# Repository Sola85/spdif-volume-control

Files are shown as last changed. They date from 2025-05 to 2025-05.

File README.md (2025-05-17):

# SPDIFVolumeControl
### What?
This is an Arduino sketch for a Raspberry Pi Pico that reads TOSLINK or SPDIF audio data, modifies the volume, and writes the audio data to a second TOSLINK/SPDIF port. The volume can be adjusted by an IR remote. Optionally the current volume and a VU meter can be displayed on a WS2812 LED strip.

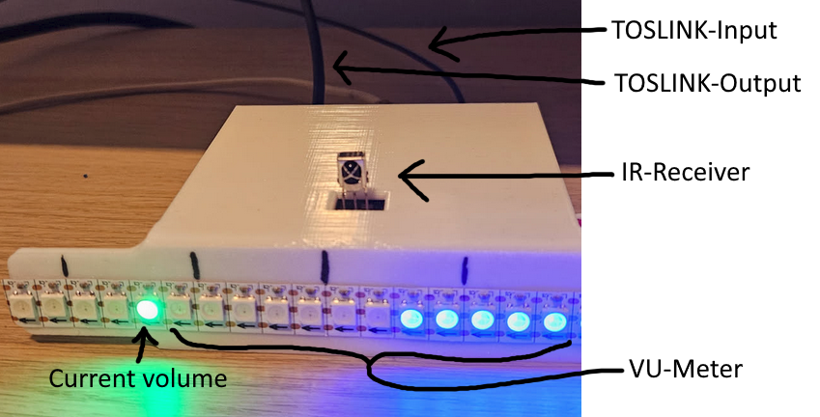
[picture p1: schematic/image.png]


### Why?
I'm in a peculiar situation: I want to connect my LG "Smart" TV to my Logitech PC speakers. However, the smart TV has only 3 types of audio outputs:

1. TOSLINK
2. HDMI ARC
3. Bluetooth 

In particular, it doesn't have an analog output. Using Bluetooth to connect to the speaker is not an option, since I don't want to deal with the hassle of always making sure a wireless connection is established. 
The Logitech speakers support various types of analog input, as well as TOSLINK. Which sounds fine, however the TV refuses to control the volume of the speakers when they are connected via TOSLINK. Since my speakers don't have a separate remote, I'm stuck.

Hence this project was born. It is designed to forward TOSLINK audio from the TV to the speakers while intercepting IR signals of the TV remote, allowing me to adjust the volume!

I'm aware that this method of adjusting the volume can:
- lead to loss of quality when significantly reducing the volume and 
- can lead to distortions when amplifying the volume.

The first point is not an issue for a non-audiophile like me. If the analog volume knob of the speaker is set to a value such that the unmodified signal is close to the target volume, I only need to adjust the volume a few increments above or below this. This typicalls leads to a quality loss of at most ~2 bits, which I can't notice. Distortions due to clipping would be more impactful, but these can be avoided by simply not amplifying the source signal using this method or by only amplifying when the source signal is very quiet.

### Compiling/Modifying

I used the following software versions to compile this project:
| Component | Version |
|---|---|
| Arduino IDE | 2.3.4 |
| [Raspberry Pi Pico Core](https://github.com/earlephilhower/arduino-pico) | 4.4.4 |
| [arduino-audio-tools](https://github.com/pschatzmann/arduino-audio-tools) | 1.0.1 (early 2025) |
| [IRremote](https://github.com/Arduino-IRremote/Arduino-IRremote) | 4.4.1 |
| [Adafruit_NeoPixel](https://github.com/adafruit/Adafruit_NeoPixel) |  1.12.5 |

Download the `code` folder and the contents should directly compile as an Arduino sketch, provided that the above dependencies are installed.

See `schematic/schematic.pdf` for wiring details.

Link to the 3D model [here](https://cad.onshape.com/documents/30e0986ab7bef6b26c69f87a/w/68a5b29d9b0bd2b4bf7dde1c/e/23cf1baabf4b8192e4efa997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).

### Usage

- Connect TOSLINK to the TV and Speakers as per schematic.
- A single orange/green led on the strip indicates the set volume. Each LED represents half an effective bit (ENOB), on a range from 17 ENOBs to 7 ENOBs.
- If a signal is detected on the input, the on board LED will start blinking and the volume indicator on the LED strip will turn from orange to green.
- The (volume-adjusted) input signal is displayed on the led strip as a VU Meter, again in the units of ENOB.

### Notes

- Currently supports **16-bit 44.1/48 kHz audio**, as this is the format my TV outputs.
- `pico_spdif_rx` should support 24-bit and higher sample rates, but the transmit side (audio-tools) is currently limited to 16-bit.
- IR control is configured for my **LG Magic Remote**, but adapting it to any protocol supported by `IRremote` should be straightforward.

### Libraries

The heavy-lifting is done by [arduino-audio-tools](https://github.com/pschatzmann/arduino-audio-tools) for transmitting and by [pico_spdif_rx](https://github.com/elehobica/pico_spdif_rx/) for receiving SPDIF signals.

I have included parts of the source of both of these libraries in this repo to accomodate a few minor changes that were necessary to get everything to work together. Despite being included in this repo, these libraries were not written by me and I do not claim ownership of them. More details are in the individual README's.

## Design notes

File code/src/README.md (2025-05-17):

# spdif_rx (modified version)

This folder contains a (minimally modified) version of the of the open-source library `pico_spdif_rx`. This was done since `pico_spdif_rx` is not available as an Arduino library and because slight modifications were necessary in order for it to work in this project.

---

## Original Library

- **Author**: Elehobica
- **Repository**: [https://github.com/elehobica/pico_spdif_rx/](https://github.com/elehobica/pico_spdif_rx/)
- **License**: BSD-2-Clause license 

---

## Modifications Made

- Adoptions of pio program according to comments in order to work with 192MHz CPU frequency
- Modification of `#include` paths, in order for Arduino IDE to be able to work with the library
- switch to `#define PICO_SPDIF_RX_DMA_IRQ 1` and `#define PICO_SPDIF_RX_PIO 1` since spdix tx uses PIO 0 and the corresponding DMA channel
- Removal of `pio_clear_instruction_memory(spdif_rx_pio);` in line 435 of `spdif_rx.cpp` as this seems to affect both PIO blocks, even though only one is passed to the function.
- rename `SPDIF_BLOCK_SIZE` as this gobal variable name is also used by spdif tx.
- Use of `pio_get_dreq` instead of manual logic for determining dreq. 
- Print-debugging

No functional or structural changes were made beyond this.

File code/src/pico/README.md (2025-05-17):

# pico-extras (modified excerpt)

This folder contains a (minimally modified) parts of the of the open-source library `pico-extras`. This was done since `pico-extras` is not available as an Arduino library (at least not that I am aware of).

---

## Original Library

- **Author**: Raspberry Pi Foundation
- **Repository**: [https://github.com/raspberrypi/pico-extras/](https://github.com/raspberrypi/pico-extras/)
- **License**: BSD-3-Clause license

---

## Modifications Made

- Deletions of files not necessary for this project
- Modification of `#include` paths, in order for Arduino IDE to be able to work with the library

No functional or structural changes were made beyond this.

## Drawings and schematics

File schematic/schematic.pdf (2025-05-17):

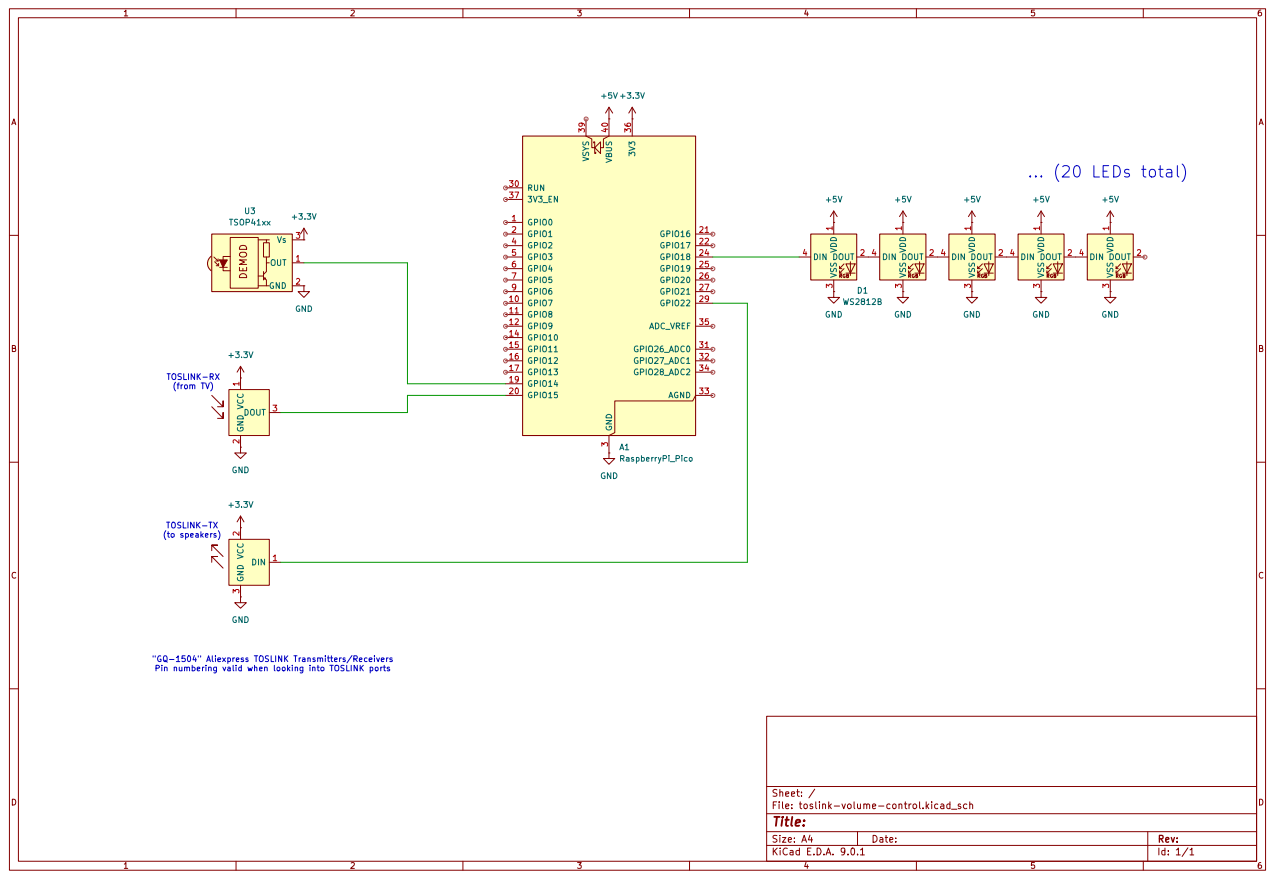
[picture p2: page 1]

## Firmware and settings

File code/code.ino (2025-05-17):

/*
 * SPDIFVolumeControl - Arduino sketch for volume control via SPDIF/TOSLINK
 * 
 * Author: Sola85
 * License: GNU General Public License v3.0 (GPL-3.0)
 * 
 * This code is part of the SPDIFVolumeControl project:
 * https://github.com/Sola85/spdif-volume-control
 *
 * Description:
 * Reads SPDIF audio, modifies volume controlled by IR remote,
 * and outputs audio to a second SPDIF port.
 */

#include <stdio.h>
#include "pico/stdlib.h"
#include "hardware/clocks.h"
#include "AudioTools.h"
#include "MySPDIFOutput.h"
#include "src/spdif_rx.h"
#include <Adafruit_NeoPixel.h>

#define IR_RECEIVE_PIN      14
#define DECODE_NEC
#define EXCLUDE_EXOTIC_PROTOCOLS
#include <IRremote.hpp>


static constexpr uint8_t PIN_PICO_SPDIF_RX_DATA = 15;
volatile static bool stable_flg = false;
volatile static bool lost_stable_flg = false;

#define NeoPixelPIN 18 
#define NUMPIXELS   20 
Adafruit_NeoPixel pixels(NUMPIXELS, NeoPixelPIN, NEO_GRB + NEO_KHZ800);

SPDIFOutput out; 
bool connected = false;
bool ever_connected = false;

void on_stable_func(spdif_rx_samp_freq_t samp_freq){
    stable_flg = true;
    connected = true;
    ever_connected = true;
}

void on_lost_stable_func(){
    lost_stable_flg = true;
    connected = false;
}

void setup(){}

const float INCREMENT = 1.414213562; // one volume increment = scale by sqrt(2)
const float MIN_VOLUME = 1./(1<<6);  // At least 16-6 = 10 bit resolution

float volumeSetting = 0.5;
float volumeSettingBackup = 0;       // To retain volume across mute
long lastVolumeChange = 0;           // Timestamp in order to ignore volume 
                                     // changes that occur to rapidly

int16_t maxReceivedSample = 0;       //Volume of received audio

bool muted(){
  return volumeSetting == 0;
}

void changeVolume(bool increase){
  if (increase){
    Serial.println("+");
    if (muted()){
      toggleMute();
      return;
    }
    volumeSetting *= INCREMENT;
    if (volumeSetting > 2) volumeSetting = 2;
  } else {
    Serial.println("-");
    if (muted()) return;
    volumeSetting /= INCREMENT;
    if (volumeSetting < MIN_VOLUME) volumeSetting = MIN_VOLUME;
  }
}

void toggleMute(){
  if (muted()){
    volumeSetting = volumeSettingBackup;
  } else {
    volumeSettingBackup = volumeSetting;
    volumeSetting = 0;
  }
}

void showVolume2(){

  uint16_t vuMeterValue = maxReceivedSample*volumeSetting;
  Serial.printf("Max: %d -> %d ~ %.1f bits\n", 
                maxReceivedSample, vuMeterValue, 
                bitsRequiredToRepresent2(vuMeterValue));
  Serial.printf("Volume: %f ~ %.1f bits\n", volumeSetting, 
                bitsRequiredToRepresent2(volumeSetting*32767)); 

  maxReceivedSample = 0;  //Reset after showing value

  pixels.fill(pixels.Color(0, 0, 0));

  float f = bitsRequiredToRepresent2(vuMeterValue);
  f = 2*(f-7); // Scale to fit on 20 LEDs
  
  for (int i = 0; i < f; i++){
    pixels.setPixelColor(i, pixels.Color(0, 0, 10));
  }
  //Show volume setting (= vuMeterValue or largest possible sample)
  f = bitsRequiredToRepresent2(volumeSetting*32767);
  f = 2*(f-7);

  auto volumeColor = connected ? pixels.Color(0, 20, 0) : pixels.Color(20, 20, 0);
  // Show volume in red if larger than 1 -> distortions possible
  pixels.setPixelColor(f, f >= 18 ? pixels.Color(20, 0, 0) : volumeColor);
  pixels.show();  
}

// Return the effective number of bits required to represent a sample
float bitsRequiredToRepresent2(uint16_t sample){
  return log2(sample) + 1; //Plus 1, since samples are signed
}

// Write audio data to spdif_tx
void writeAudioData(){
  uint32_t read_count = 0;
  uint32_t* buff;
  uint32_t total_count = spdif_rx_get_fifo_count();
  while (read_count < total_count) {
      uint32_t get_count = spdif_rx_read_fifo(&buff, total_count - read_count);
      for (int j = 0; j < get_count; j++) {
          int16_t sample = ((buff[j] & 0x0ffffff0) >> 12);
          if (sample > maxReceivedSample) maxReceivedSample = sample;
          sample *= volumeSetting;
          out.write((uint8_t*)&sample, sizeof(sample));
      }
      read_count += get_count;
  }
}

void loop()
{
    //for(int i = 0; i < 2; i++){DEBUGV("Waiting to start rx...\n");delay(1000);}
    pinMode(LED_BUILTIN, OUTPUT);

    set_sys_clock_khz(192000, false); 
    IrReceiver.begin(IR_RECEIVE_PIN, false);

    long last_update = millis();

    spdif_rx_config_t config = {
        .data_pin = PIN_PICO_SPDIF_RX_DATA,
        .pio_sm = 3,
        .dma_channel0 = 2,
        .dma_channel1 = 3,
        .alarm_pool = alarm_pool_get_default(),
        .flags = SPDIF_RX_FLAGS_ALL
    };


    spdif_rx_start(&config);
    spdif_rx_set_callback_on_stable(on_stable_func);
    spdif_rx_set_callback_on_lost_stable(on_lost_stable_func);


    AudioInfo info(48000, 2, 16);
    

    auto config_ = out.defaultConfig();
    config_.copyFrom(info); 
    config_.pin_data = 21;
    config_.buffer_size = 384;
    config_.buffer_count = 8;

    bool res = out.begin(config_);

    pixels.begin();

    while (true) {
        if (stable_flg) {
            stable_flg = false;
            Serial.printf("detected stable sync\n");
        }
        if (lost_stable_flg) {
            lost_stable_flg = false;
            Serial.printf("lost stable sync. waiting for signal\n");
            if (!ever_connected){ // If there is no signal present when we boot, for some reason we will immediately disconnect if the signal does appear.
              delay(1000);        // As a workaround, simply reboot if we've never seen a signal and we get a disconnect. 
              rp2040.reboot();    // Then we know the signal will be present after reboot and everything works fine.
            }
        }
        if (spdif_rx_get_state() == SPDIF_RX_STATE_STABLE){
          if (millis() - last_update > 100) {
            last_update = millis();
            digitalWrite(LED_BUILTIN, (millis()/100)%2); //Activity indicator when sync is stable
            //spdif_rx_samp_freq_t samp_freq = spdif_rx_get_samp_freq();
            //float samp_freq_actual = spdif_rx_get_samp_freq_actual();
            //Serial.printf("Samp Freq = %d Hz (%7.4f KHz)\n", (int) samp_freq, samp_freq_actual / 1e3);            
          }
          writeAudioData();
        }
        if (IrReceiver.decode()) {
    
          IrReceiver.resume();
          Serial.printf("%x %x\n", IrReceiver.decodedIRData.address, IrReceiver.decodedIRData.command);

          //Decode IR data
          if (millis() - lastVolumeChange > 250 && (IrReceiver.decodedIRData.address == 0xA6 || IrReceiver.decodedIRData.address == 0x04)) {
            lastVolumeChange = millis();
            switch(IrReceiver.decodedIRData.command){
              case 0x0B:
              case 0x03:
                changeVolume(false);
                break;
              case 0x0A:
              case 0x02:
                changeVolume(true);
                break;
              case 0x1E:
              case 0x09:
                toggleMute();
              default:  
                break;
            }
          }
        } 
    }
}

void setup1(){}

void loop1(){
  delay(100);
  showVolume2(); //Needs to happen on second core
                 // otherwise audio drops out occasionally
}

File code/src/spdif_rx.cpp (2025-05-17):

/*------------------------------------------------------/
/ Copyright (c) 2023, Elehobica
/ Released under the BSD-2-Clause
/ refer to https://opensource.org/licenses/BSD-2-Clause
/------------------------------------------------------*/

#include "spdif_rx.h"
#include "Arduino.h"

#include <stdio.h>
#include <string.h>
#include "hardware/pio.h"
#include "hardware/dma.h"
#include "hardware/irq.h"
#include "hardware/sync.h"
#include "pico/stdlib.h"
#include "pico/audio.h"
#include "spdif_rx_capture.pio.h"
#include "spdif_rx_48000.pio.h"
#include "spdif_rx_96000.pio.h"
#include "spdif_rx_192000.pio.h"

extern SerialUSB _serialUSB;
//PIO_DREQ_NUM(pio, sm, is_tx) ((sm) + (((is_tx) ? 0 : NUM_PIO_STATE_MACHINES) + PIO_NUM(pio) * (DREQ_PIO1_TX0 - DREQ_PIO0_TX0)))

#define SYSTEM_CLK_FREQUENCY (192000000)
// sample words to detect is equivalent to 64*4+8 symbols (2 frames + sync) at 44.1 KHz @ 125 MHz clock
// because at least one Sync M Code has to be included in sampled words (-> need 2 frames considering when head block hits)
#define SPDIF_RX_CAPTURE_SIZE (((SYSTEM_CLK_FREQUENCY / SAMP_FREQ_44100 / 128 + 1) * (64 * 4 + 8) + 31) / 32)

#define spdif_rx_pio __CONCAT(pio, PICO_SPDIF_RX_PIO)
#define DREQ_PIOx_RX0 __CONCAT(__CONCAT(DREQ_PIO, PICO_SPDIF_RX_PIO), _RX0)

#define DMA_IRQ_x __CONCAT(DMA_IRQ_, PICO_SPDIF_RX_DMA_IRQ)

#define NUM_AVE (8)
#define NUM_STABLE_FREQ (16) // 1 ~ 31

static spdif_rx_config_t gcfg;
static alarm_id_t alarm_id;

typedef enum _spdif_rx_pio_program_id_t  {
    SPDIF_RX_PIO_CAPTURE = 0,
    SPDIF_RX_PIO_DECODE_48000,
    SPDIF_RX_PIO_DECODE_96000,
    SPDIF_RX_PIO_DECODE_192000,
} spdif_rx_pio_program_id_t;

typedef struct _spdif_rx_pio_program_t {
    const spdif_rx_pio_program_id_t id;
    const pio_program_t* program;
    uint offset;
    uint entry_point;
    pio_sm_config (*get_default_config)(uint);
} spdif_rx_pio_program_t;

static spdif_rx_pio_program_t program_sets[] = {
    {SPDIF_RX_PIO_CAPTURE,           &spdif_rx_capture_program,    0, spdif_rx_capture_offset_entry_point,    spdif_rx_capture_program_get_default_config},
    {SPDIF_RX_PIO_DECODE_48000,      &spdif_rx_48000_program,      0, spdif_rx_48000_offset_entry_point,      spdif_rx_48000_program_get_default_config},
    {SPDIF_RX_PIO_DECODE_96000,      &spdif_rx_96000_program,      0, spdif_rx_96000_offset_entry_point,      spdif_rx_96000_program_get_default_config},
    {SPDIF_RX_PIO_DECODE_192000,     &spdif_rx_192000_program,     0, spdif_rx_192000_offset_entry_point,     spdif_rx_192000_program_get_default_config}
};

typedef enum _spdif_rx_samp_freq_id_t {
    SAMP_FREQ_ID_44100 = 0,
    SAMP_FREQ_ID_48000,
    SAMP_FREQ_ID_88200,
    SAMP_FREQ_ID_96000,
    SAMP_FREQ_ID_176400,
    SAMP_FREQ_ID_192000,
    _NUM_SAMP_FREQ_IDS_
} spdif_rx_samp_freq_id_t;

typedef struct _spdif_rx_samp_freq_info_set_t {
    const spdif_rx_samp_freq_id_t id;
    const spdif_rx_samp_freq_t sf;
    const int samp_freq_lower;
    const int samp_freq_upper;
    const int min_edge_interval_lower;
    const int min_edge_interval_upper;
    const int max_edge_interval_lower;
    const int max_edge_interval_upper;
} spdif_rx_samp_freq_info_set_t;

#define GEN_SF_INFO_SET(sf) \
    { \
        SAMP_FREQ_ID_##sf, \
        SAMP_FREQ_##sf, \
        SAMP_FREQ_##sf *  99 / 100, \
        SAMP_FREQ_##sf * 101 / 100, \
        (SYSTEM_CLK_FREQUENCY / SAMP_FREQ_##sf * 2 / 128) *  91 / 100, \
        (SYSTEM_CLK_FREQUENCY / SAMP_FREQ_##sf * 2 / 128) * 111 / 100, \
        (SYSTEM_CLK_FREQUENCY / SAMP_FREQ_##sf * 6 / 128) *  97 / 100, \
        (SYSTEM_CLK_FREQUENCY / SAMP_FREQ_##sf * 6 / 128) * 104 / 100 \
    }
// -9%, +11% is the minimum range which makes at least +- 1 cycles at 192000 Hz in 2 symbol length
// -3%, +4% is the maximum range which doesn't overlap between near-by frequencies in 6 symbol length

static const spdif_rx_samp_freq_info_set_t sf_info_sets[] = {
    GEN_SF_INFO_SET(44100),
    GEN_SF_INFO_SET(48000),
    GEN_SF_INFO_SET(88200),
    GEN_SF_INFO_SET(96000),
    GEN_SF_INFO_SET(176400),
    GEN_SF_INFO_SET(192000)
};

typedef enum _spdif_rx_samp_freq_criteria_check_t  {
    CHK_SAMP_FREQ = 0,
    CHK_SAMP_FREQ_LOWER_ONLY,
    CHK_SAMP_FREQ_UPPER_ONLY,
    CHK_MIN_EDGE_INTERVAL,
    CHK_MIN_EDGE_INTERVAL_LOWER_ONLY,
    CHK_MIN_EDGE_INTERVAL_UPPER_ONLY,
    CHK_MAX_EDGE_INTERVAL,
    CHK_MAX_EDGE_INTERVAL_LOWER_ONLY,
    CHK_MAX_EDGE_INTERVAL_UPPER_ONLY
} spdif_rx_samp_freq_criteria_check_t;

// Sync codes which appears the output of decode PIO program
static const uint32_t SYNC_B = 0b1111;
static const uint32_t SYNC_M = 0b1011;
static const uint32_t SYNC_W = 0b0111;

// timer parameters
static const uint32_t capture_retry_interval_ms = 100;
static const uint32_t capture_timeout_us        = 100 + 300; // us (300 us to give more time margin before cancelling timeout from spdif_rx_dma_irq_handler by _clear_timer() since sdk-2.0.0 corresponding to alarm_pool usage)
static const uint32_t decode_wait_stable_ms     = 200;
static const uint32_t decode_timeout_ms         = 10;

static spdif_rx_state_t state;

static void (*on_stable_func)(spdif_rx_samp_freq_t samp_freq) = NULL;
static void (*on_lost_stable_func)() = NULL;

static uint32_t fifo_buff[SPDIF_RX_FIFO_SIZE];
static uint32_t buff_wr_pre_ptr = 0;
static uint32_t buff_wr_done_ptr = 0;
static uint32_t buff_rd_ptr = 0;
static uint32_t buff_count;

static dma_channel_config dma_config0;
static dma_channel_config dma_config1;

static bool setup_done = false;
static bool stable_done = false;
static spdif_rx_pio_program_t* current_pg;
static int block_count;
static uint64_t prev_time_us = 0;
static uint32_t waiting_start_time_ms = 0;
static uint32_t block_interval[NUM_AVE];
static bool block_aligned;
static int block_align_count;
static float samp_freq_actual;
static spdif_rx_samp_freq_t samp_freq;
static uint32_t stable_freq_history;
static bool stable_freq_flg;
static uint trans_count = SPDIF_BLOCK_SIZE_;
static uint8_t c_bits[SPDIF_BLOCK_SIZE_ / 16];
static uint32_t parity_err_count;

// prototype declaration
static int64_t _spdif_rx_capture_retry(alarm_id_t /*id*/, void* /*user_data*/);
void __isr __time_critical_func(spdif_rx_dma_irq_handler)();

static inline uint64_t _micros(void)
{
    return to_us_since_boot(get_absolute_time());
}

static inline uint32_t _millis(void)
{
    return to_ms_since_boot(get_absolute_time());
}

// === Internal functions ===
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
